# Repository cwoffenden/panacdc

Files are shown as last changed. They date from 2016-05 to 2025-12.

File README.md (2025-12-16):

Panasonic CX-DP60 Emulator
==========================

The project is a combination of hardware and software to emulate a Panasonic CX-DP60 CD Changer (CDC), allowing early 1990s car radios to use the CD inputs as an auxilary. Tested with a Panasonic CQ-LR2450A (from an MG RV8) but should work with others from the same era.

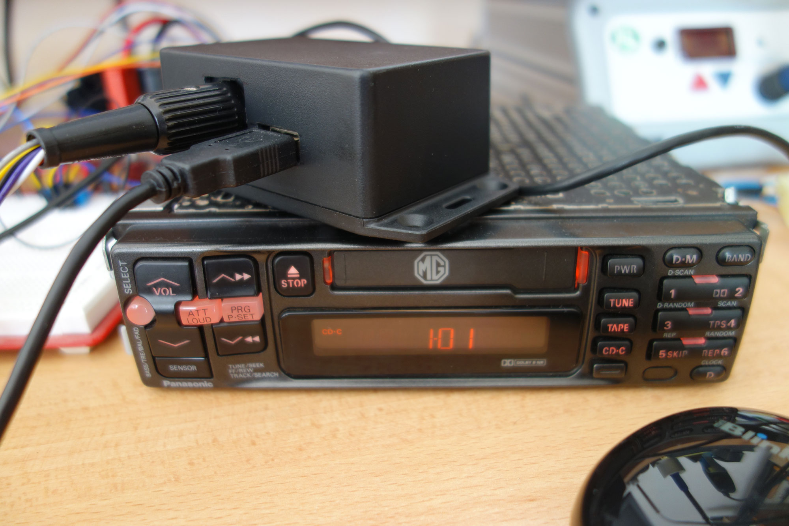
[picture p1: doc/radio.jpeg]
Boxed CDC emulator


Without a CDC connected the radio ignores changing to the CD input, hence the need to emulate its presence. This isn't a new idea; others have created emulators for newer CDCs (see [CDCEmu](http://q1.se/cdcemu/), [VAG CDC Faker](http://dev.shyd.de/2013/09/avr-raspberry-pi-vw-beta-vag-cdc-faker/), etc.) but these don't work with older radios.

I started by looking at the [DP60's schematics](https://raw.githubusercontent.com/cwoffenden/panacdc/master/doc/schematic.pdf) (actually, I started with CDCEmu, which didn't work, so I rolled up my sleeves and did this) and recording the traffic with a [Saleae Logic](https://www.saleae.com/). The radio's remote commands look to be using a variant of the [NEC protocol](https://www.vishay.com/docs/80071/dataform.pdf) whereas the CDC's data is a byte orientated synchronous serial stream:

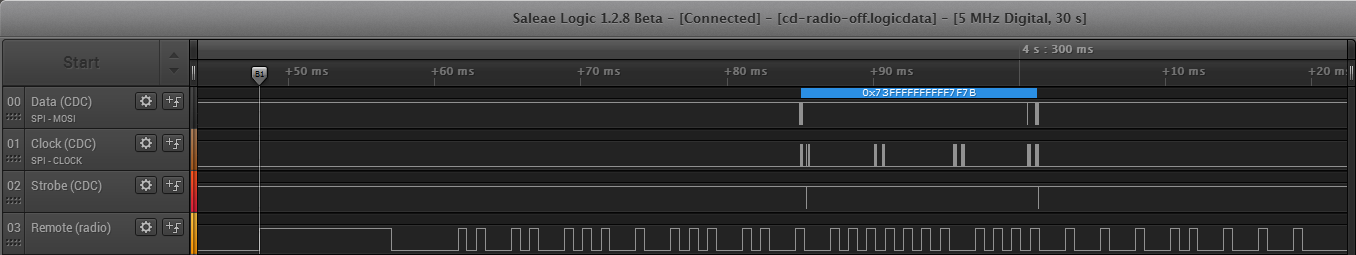
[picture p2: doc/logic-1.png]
NEC-like remote data


A close-up of the CDC's serial data can bee seen [here](https://raw.githubusercontent.com/cwoffenden/panacdc/master/doc/logic-2.png), with a [Logic](https://www.saleae.com/downloads) capture of the traffic between the CDC and radio [here](https://github.com/cwoffenden/panacdc/raw/master/doc/cd-radio-off.logicdata) (note that the Logic hardware isn't required to view the capture).

It's not necessary to understand or fully decode the communication, just to recognise and replay. The documented source and schematic are available above, but for anyone wishing to simply build it, it's enough to order a PCB (either from the [Eagle](http://www.cadsoftusa.com/) [project files](https://github.com/cwoffenden/panacdc/tree/master/pcb), the resulting [Gerbers](https://github.com/cwoffenden/panacdc/raw/master/out/board.zip), or direct from [OSH Park](https://oshpark.com/shared_projects/Xu28lOTu)) and program the flash (via the ISP connector on the board using the [prebuilt firmware](https://github.com/cwoffenden/panacdc/blob/master/out/flash.elf) and [any](https://www.amazon.co.uk/dp/B00AVRHVPO) [low-cost](https://www.sparkfun.com/categories/7) [programmer](https://www.arduino.cc/en/Tutorial/ArduinoISP)). It was designed to be built with nothing more than a regular soldering iron.

Parts can be ordered from [Farnell](http://www.farnell.com/), [Mouser](http://www.mouser.com/) or any other componment supplier (the BOM is available [here](https://github.com/cwoffenden/panacdc/blob/master/out/parts.csv), which can be sent directly to Farnell's [BOM upload](http://uk.farnell.com/help-parts-list-bom-upload)). The finished project has a USB connector to power a Bluetooth or DLNA receiver (tested with an [Arcam miniBlink](http://www.arcam.co.uk/mini.htm)). A [conformal coating](https://raw.githubusercontent.com/cwoffenden/panacdc/master/doc/board.jpeg) was added to protect the board from any moisture.

How Does It Work?
-----------------

When powered on the board sends `0x73FFFFFFFFFF7F7B` every 40ms to the radio (on the _data_, _clock_ and _strobe_ lines; see [sendBytes()](https://github.com/cwoffenden/panacdc/blob/master/src/main.c#L177)) to say there is a CDC connected. When the radio switches to the CD input, with either a `0x08` or `0xA4` command (see [ISR(INT0_vect)](https://github.com/cwoffenden/panacdc/blob/master/src/main.c#L272)) the board then starts sending `0x33FFCF81CF7F7F3B`, meaning the first CD is playing track one (it probably contains time data and so on, but it's not necessary to know, just to replay what was captured). The only other radio command understood is `0x10`, sent when switching back to the tuner or cassette, or when powering off, to which the response is `0x13FFFFFFFFFF7F1B` (without which it's not possible to turn the radio off).

Output from the emulator to the radio is [bit banged](https://en.wikipedia.org/wiki/Bit_banging), with timing close enough to the DP60 that the radio is happy (but simplified; the real timing is much more complex, just not required). Input to the emulator from the radio uses a hardware interrupt (`INT0`) and one of the hardware timers (`TIMER1`) to decode the _remocon_ signal.

Improvements
------------

Send delays would be better implemented using the ATtiny's other hardware timer, then the board could drop into low-power mode (not really needed but is the _correct_ way of doing things). Multiple audio sources could be supported by changing virtual CDs (with the circuit extended so the ATtiny switches analogue sources).

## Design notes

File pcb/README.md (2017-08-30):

Schematic and board layout for [CadSoft Eagle](http://www.cadsoftusa.com/). The project file is for 6.5 but should work in newer versions.

### Note
The 8-pin DIN used isn't the exact type found on the DP60 (and therefore the original cabling). The DP60 has pins arranged in a U-shape (262 degrees) whereas the socket used is C-shaped (270 degrees). It's close and with a little force the cable can be made to fit. Sourcing a PCB mount U-shaped socket no longer seems possible (removing one fitted to a broken DP60 is an option, though the PCB would need altering accordingly).

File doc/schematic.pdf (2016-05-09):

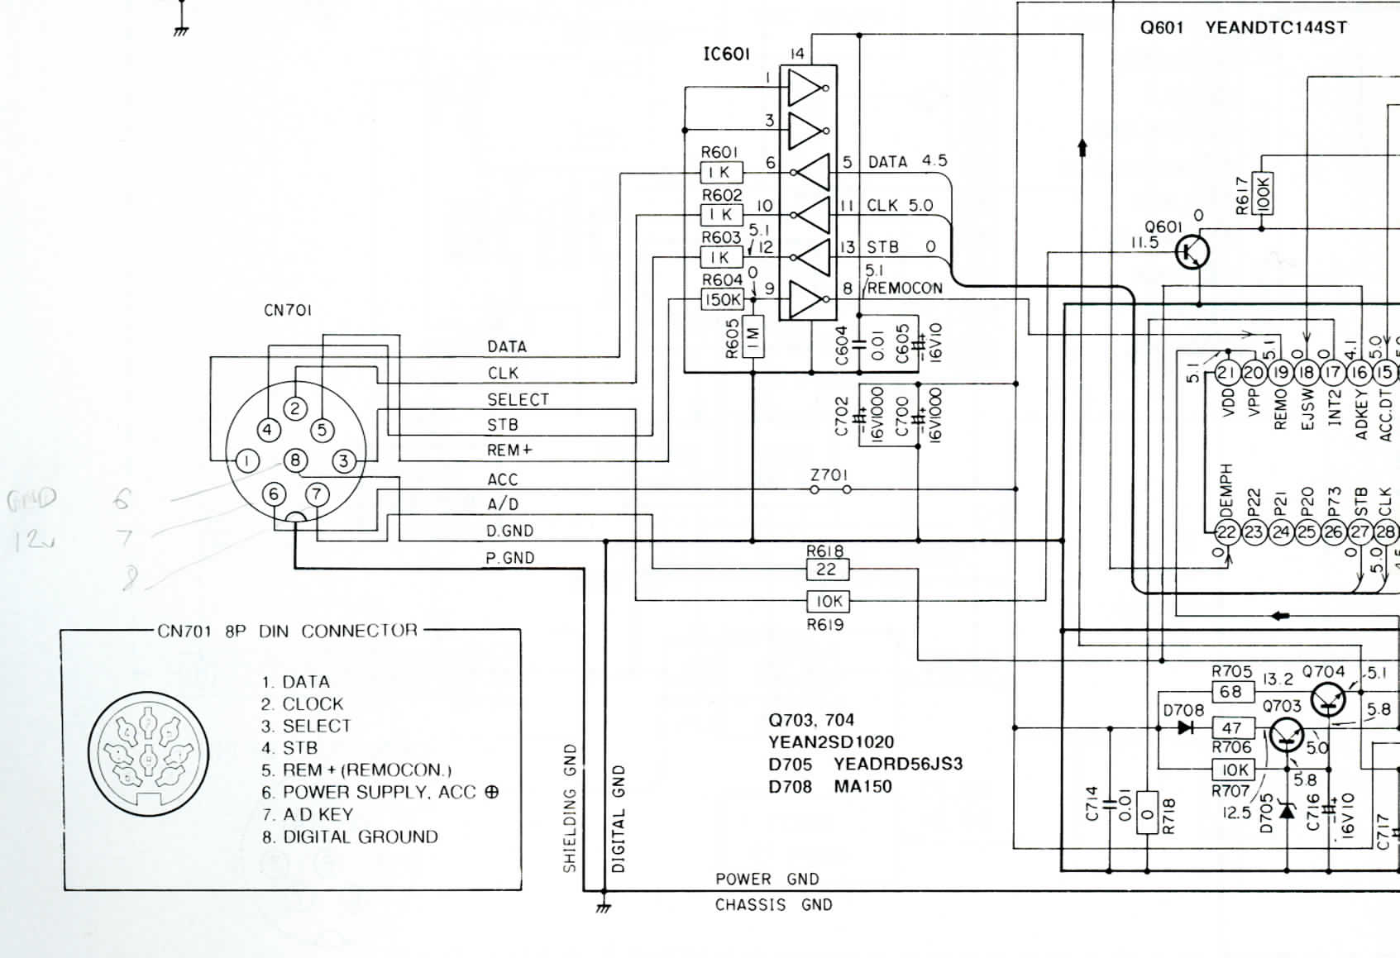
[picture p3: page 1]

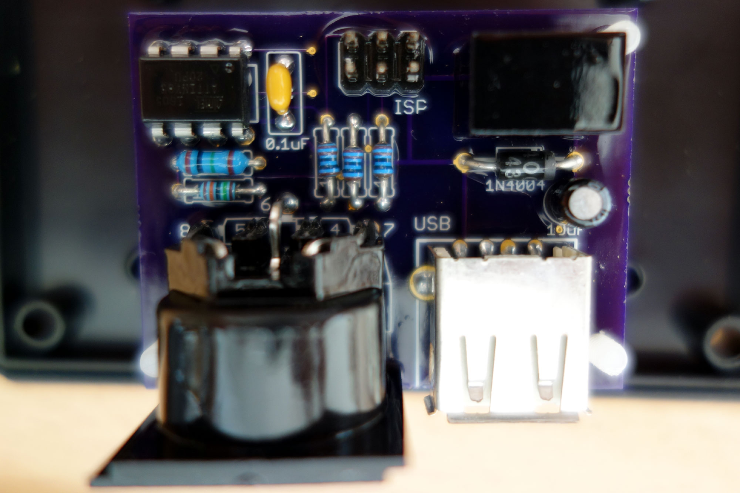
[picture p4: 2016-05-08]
doc/board.jpeg

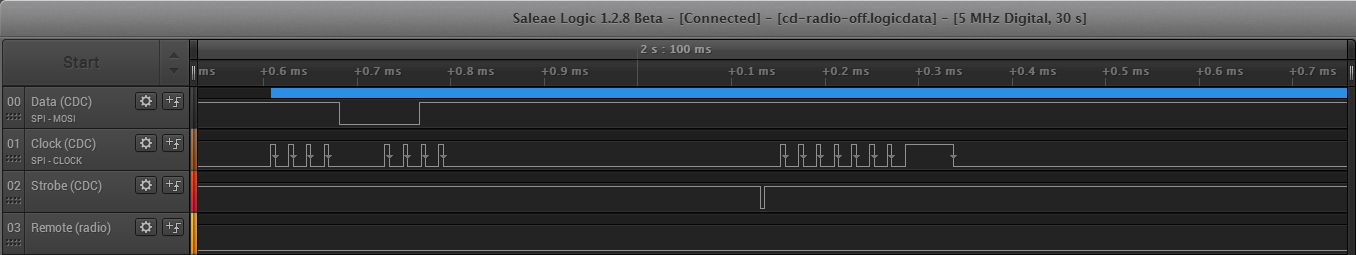
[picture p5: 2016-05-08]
doc/logic-2.png

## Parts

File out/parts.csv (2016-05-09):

Part | Value | Farnell
C1 | 0.1uF | 1216445
C2 | 10uF | 1902051
CDC | MAB8SH | 809913
D1 | 1N4004 | 9565027
ISP | AVR_SPI_PRG_6NS | 1593440
MCU | ATtiny85 | 1455162
R1 | 1K | 9342400
R2 | 1K | 9342400
R3 | 1K | 9342400
R4 | 150K | 9342648
R5 | 1M | 9342435
REG | VREG-RECOM-785.0-1.0 | 1793142
USB | PN87520-S | 2112381

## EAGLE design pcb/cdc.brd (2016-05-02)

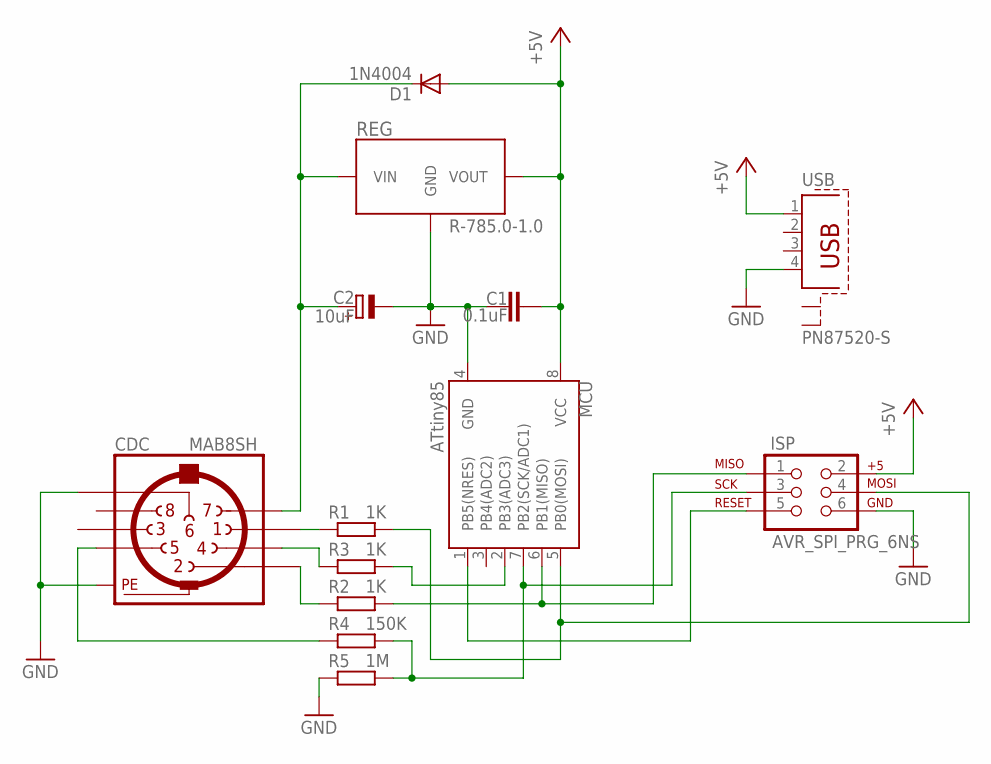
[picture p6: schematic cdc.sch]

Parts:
C1: 0.1uF; C5B3
C2: 10uF; E1,8-4
CDC: MAB8SH
D1: 1N4004; DO41-10
ISP: AVR_SPI_PRG_6NS; 2X3-NS
MCU: ATtiny85; DIP08
R1, R2, R3: 1K; 0207/7
R4: 150K; 0207/7
R5: 1M; 0207/7
REG: VREG-RECOM-785.0-1.0
USB: PN87520-S

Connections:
+5V: C1.2, D1.A, ISP.2, MCU.8 (VCC), REG.VOUT, USB.1
GND: C1.1, C2.-, CDC.6, CDC.PE, CDC.PE@ (PE), ISP.6, MCU.4 (GND), R5.1, REG.GND, USB.4
unnamed: C2.+, CDC.7, D1.C, REG.VIN
unnamed: ISP.4, MCU.5 (PB0(MOSI)), R1.2
unnamed: ISP.1, MCU.6 (PB1(MISO)), R2.2
unnamed: MCU.2 (PB3(ADC3)), R3.2
unnamed: ISP.5, MCU.1 (PB5(NRES))
unnamed: ISP.3, MCU.7 (PB2(SCK/ADC1)), R4.2, R5.2
unnamed: CDC.2, R2.1
unnamed: CDC.4, R3.1
unnamed: CDC.1, R1.1
unnamed: CDC.5, R4.1

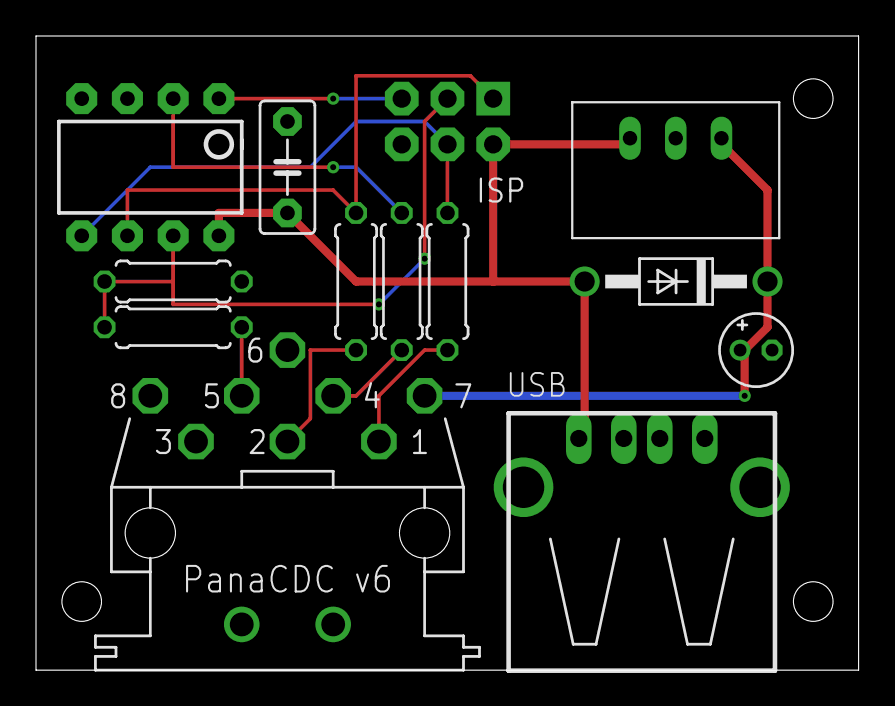
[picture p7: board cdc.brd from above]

Board: 2 copper layers, 45.7 x 35.2 mm, 13 parts (0 on the bottom side), 12 nets.

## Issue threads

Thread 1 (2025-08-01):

Add track titles/time codes

anju0001, 2025-08-01:
Hi Carl, since I cannot see any means of contact I thought I would open an issue here :)
Would it be possible for you to add a logic capture where you can see track titles or maybe give a timecode for a track title in the original logic capture? I wanted to implement an emulator for a CDC using an MP3 player and would like to see track titles.

Thanks and regards,
Andreas

Closed 2025-08-13.

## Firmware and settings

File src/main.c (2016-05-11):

/**
 * \file main.c
 * CX-DP60 emulator for ATtiny85.
 */
#define F_CPU 8000000UL

#include <stdbool.h>
#include <avr/interrupt.h>
#include <util/delay.h>

/**
 * \def CDC_DAT
 * 8-pin DIN pin 1 (\e data from CDC).
 */
#define CDC_DAT PB0
/**
 * \def CDC_CLK
 * 8-pin DIN pin 2 (\e clock from CDC).
 */
#define CDC_CLK PB1
/**
 * \def CDC_STB
 * 8-pin DIN pin 4 (\e strobe from CDC).
 */
#define CDC_STB PB3
/**
 * \def REMOCON
 * 8-pin DIN pin 5 (\e remocon from radio).
 */
#define REMOCON PB2

//***************************************************************************/

/**
 * CDC player states.
 */
typedef enum {
	/**
	 * CDC has been powered on.
	 */
	STATE_INIT,
	/**
	 * The radio selected the CDC input.
	 */
	STATE_PLAY,
	/**
	 * The radio \e deselected the CDC (either by selecting the radio, tape or
	 * powering off).
	 */
	STATE_STOP
} state_t;

/**
 * Container for the eight byte message sent to the radio.
 */
struct payload {
	uint8_t b0; /**< byte 1 */
	uint8_t b1; /**< byte 2 */
	uint8_t b2; /**< byte 3 */
	uint8_t b3; /**< byte 4 */
	uint8_t b4; /**< byte 5 */
	uint8_t b5; /**< byte 6 */
	uint8_t b6; /**< byte 7 */
	uint8_t b7; /**< byte 8 */
};

/**
 * Message sent when the CDC is first powered up. This (and the other \c
 * payload entries, were recorded with Saleae Logic).
 */
struct payload dataInit = {
	0x73, 0xFF, 0xFF, 0xFF, 0xFF, 0xFF, 0x7F, 0x7B
};

/**
 * Message sent during CD playback. The \c payload no doubt contains CD, track
 * and time data, but we don't need to even know.
 */
struct payload dataPlay = {
	0x33, 0xFF, 0xCF, 0x81, 0xCF, 0x7F, 0x7F, 0x3B
};

/**
 * Message sent when either powering off or switching sources.
 */
struct payload dataStop = {
	0x13, 0xFF, 0xFF, 0xFF, 0xFF, 0xFF, 0x7F, 0x1B
};

//********************************** State **********************************/

/**
 * CDC player state.
 */
state_t state = STATE_INIT;

/**
 * Timer 1 overflow count (each is equal to 256us).
 */
uint16_t oflow1 = 0;

/**
 * Number of \e us the \e remote signal was \e high.
 */
uint16_t remHi = 0;

/**
 * Number of \e us the \e remote signal was \e low.
 */
uint16_t remLo = 0;

/**
 * \true if the \e remocon signal is being decoded (otherwise the decoder is
 * waiting on the start bit).
 */
bool decode = false;

/**
 * Current bit being processed from the \e remocon signal.
 */
uint8_t cmdBit = 0;

/**
 * Buffer into which the \e remocon signal is composed, one bit at a time.
 */
uint32_t cmdBuf = 0;

//********************************* Sending *********************************/

/**
 * Sends a single bit on the \e data line followed by a \e clock (high then
 * low, with the radio reading on the low). The operation takes approximately
 * 20us (when counting in the call overhead from \c #sendByte()).
 * 
 * \param[in] val bit value
 */
void sendBit(bool val) {
	if (val) {
		PORTB |=  _BV(CDC_DAT);
	} else {
		PORTB &= ~_BV(CDC_DAT);
	}
	PORTB |=  _BV(CDC_CLK);
	_delay_us(5);
	PORTB &= ~_BV(CDC_CLK);
	_delay_us(11);
}

/**
 * Sends a single byte on the \e data line, as eight bit/clock operations
 * followed by an optional \e strobe.
 * 
 * \param[in] val byte value
 * \param[in] stb \c true \e strobe should pulse low after sending the byte
 */
void sendByte(uint8_t val, bool stb) {
	PORTB |= _BV(CDC_STB);
	for (int8_t n = 7; n >= 0; n--) {
		sendBit((val >> n) & 1);
	}
	if (stb) {
		_delay_us(100);
		PORTB &= ~_BV(CDC_STB);
		_delay_us(5);
		PORTB |=  _BV(CDC_STB);
	} else {
		_delay_us(5);
	}
	_delay_us(15);
}

/**
 * Sends an eight byte message, with \e clock and \e strobe signals.
 * 
 * \param[in] data complete message to send
 */
void sendBytes(struct payload* data) {
	uint8_t* val = &data->b0;
	for (int8_t n = 7; n >= 0; n--) {
		sendByte(*val++, (n == 0) || (n == 7));
		if (n != 0) {
			/*
			 * This timing is nothing like a real CDC but it works just fine
			 * with the MG radio. A real CDC has a long 4ms delay between each
			 * pair of bytes sent.
			 */
			_delay_us(50);
		}
	}
}

//******************************** Receiving ********************************/

/**
 * \def APPROX
 * Compares approximately \a val with \a cmp, give or take 40%. Used to
 * compare timings where fluctuations are present.
 * 
 * \param val \c uint16_t value
 * \param cmp \c uint16_t to compare with \a val
 */
#define APPROX(val, cmp) ((val > (uint16_t) ((cmp * 60UL) / 100U)) && (val < (uint16_t) ((cmp * 140UL) / 100U)))

/**
 * Resets the \e remocon decoder state.
 */
void resetDecoder() {
	oflow1 = 0;
	decode = false;
	cmdBit = 0;
}

/**
 * The 8-bit timer for \e remocon signals has overflowed (which is the
 * expected behaviour after 256us).
 */
ISR(TIMER1_OVF_vect) {
	oflow1++;
	/*
	 * If the overflow reached 65ms (i.e. it overflowed 254 times) then the
	 * decoding state is reset. In use, signals over 20ms are either an error
	 * or the wait between pulses (which we're not interested in anyway).
	 */
	if (oflow1 >= 254) {
		resetDecoder();
	}
}

/**
 * \c INT0 handler (transition of \e remocon signal), decoding the RC5-style
 * stream into radio commands.
 */
ISR(INT0_vect) {
	/*
	 * Any processing is done on the rising edge (remocon high), but we're
	 * interested in the previous pulse's falling edge (and its mark/space
	 * ratio). Any unknown pulses and we reset the decoder.
	 */
	if (PINB & _BV(REMOCON)) {
		remLo = (oflow1 << 8) + TCNT1;
		if (APPROX(remHi, 9000) && APPROX(remLo, 4500)) {
			/*
			 * Found a 9ms/4.5ms pulse. No matter what is being processed,
			 * this always signifies a start bit (resetting the decoding
			 * state).
			 */
			decode = true;
			cmdBit = 0;
		} else {
			if (decode) {
				if (APPROX(remHi, 650)) {
					if (APPROX(remLo, 1750)) {
						cmdBuf <<= 1;
						cmdBuf  |= 1;
						cmdBit++;
					} else {
						if (APPROX(remLo, 650)) {
							cmdBuf <<= 1;
							cmdBit++;
						} else {
							resetDecoder();
						}
					}
					if (cmdBit == 32) {
						/*
						 * After 32 bits have been processed we have a full
						 * radio command. The first two bytes are always
						 * 0x532C, the last two bytes are the inverse of one
						 * another (and contain the actual command).
						 */
						if ((cmdBuf >> 16) == 0x532C) {
							if (((cmdBuf >> 8) & 0xFF) == ((~cmdBuf) & 0xFF)) {
								/*
								 * Known buttons/commands:
								 * 
								 *   08 Power on
								 *   A4 CDC select
								 *   10 CDC deselect (and power off)
								 *   68 >>
								 *   A8 <<
								 *   38 PRG
								 *   D0 TPS
								 *   98 SKIP
								 *   48 REP
								 *   F0 D
								 */
								switch ((cmdBuf >> 8) & 0xFF) {
								case 0x08:
								case 0xA4:
									state = STATE_PLAY;
									break;
								case 0x10:
									state = STATE_STOP;
									break;
								default:
									/*
									 * Maintain the current state.
									 */
									break;
								}
							}
						}
						resetDecoder();
					}
				} else {
					resetDecoder();
				}
			} else {
				resetDecoder();
			}
		}
	} else {
		remHi = (oflow1 << 8) + TCNT1;
	}
	TCNT1  = 0;
	oflow1 = 0;
}

//***************************************************************************/

/**
 * Delays for the requested number of milliseconds. Calling \c _delay_ms()
 * alone seems to block interrupts for the requested duration, so multiple
 * shorter calls are made.
 * 
 * \todo test whether this is needed
 * 
 * \param[in] ms number of milliseconds
 */
void _delay(int8_t ms) {
	for (; ms > 0; ms--) {
		_delay_ms(1);
	}
}

/**
 * Main loop.
 * \n
 * \note \e select is being ignored (from the radio) since the CDC always
 * sends data anyway (\e select is high when the radio is powered on, and
 * since the radio can't power off without communicating with the CDC, its
 * use can be inferred).
 * 
 * \todo the send loops should be timer/state machine driven so the MCU can sleep (then everything is interrupt driven)
 */
int main(void) {
	/*
	 * Wait for things to settle after power-on before starting.
	 */
	_delay_ms(100);
	/*
	 * Data, clock and strobe as output, set high. Remote as input, tri-state
	 * (externally weakly pulled low). Remaining ports pulled high (inc. PB4
	 * which is disconnected).
	 */
	DDRB  =  _BV(CDC_DAT)
		  |  _BV(CDC_CLK)
		  |  _BV(CDC_STB);
	PORTB = ~_BV(REMOCON);
	/*
	 * Timer1 with CK/8 @ 8MHz gives 1us per tick (with overflow). It's a good
	 * compromise, allowing for simpler calculations (e.g. a 600us period is
	 * 600 ticks).
	 */
	TCCR1  =  _BV(CS12);	// CK/8
	TIMSK  =  _BV(TOIE1);	// enable overflow
	MCUCR |=  _BV(ISC00);	// any logical change on INT0
	MCUCR &= ~_BV(ISC01);
	GIMSK |=  _BV(INT0);	// enable INT0
	sei();
	/*
	 * Sit waiting, switching between waiting for a connection, 'playing' a
	 * CD, and powering off (which goes back to waiting).
	 */
	while(1) {
		switch (state) {
		case STATE_INIT:
			sendBytes(&dataInit);
			break;
		case STATE_PLAY:
			sendBytes(&dataPlay);
			break;
		default:
			/*
			 * Note: the capture shows a few of these 'stop' payloads sent
			 * (followed by another packet, seemingly not needed, before going
			 * back to the 'init').
			 */
			sendBytes(&dataStop);
			_delay(40);
			sendBytes(&dataStop);
			state = STATE_INIT;
		}
		_delay(40);
	}
}

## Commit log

2016-05-02 Initial commit
    Initial board and firmware commit.
    [cdc.brd, cdc.sch]
2016-05-08 Accounted for different MCU timings
    Testing on a different ATtiny85 showed huge timing differences for the
    timer, so the timings were relaxed further.
2016-05-09 Added BOM
    [parts.csv]
2016-05-09 Updated docs
    Added schematic, updated docs.
2016-05-09 Added Farnell BOM upload link
2016-05-15 Added note on socket choice
2016-05-16 Further clarification on the DIN connector

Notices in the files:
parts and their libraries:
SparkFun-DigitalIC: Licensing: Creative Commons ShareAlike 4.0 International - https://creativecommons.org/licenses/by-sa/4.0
